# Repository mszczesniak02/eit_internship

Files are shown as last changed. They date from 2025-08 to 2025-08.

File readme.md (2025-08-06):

# EIT Internship 2025

This repository contains documentation and resources for 3D printing equipment, developed during the EIT internship program.

## Project Overview

The project encompasses two main components:

-   **Voron 3D Printer**: Operational manual, configuration files, and system backups
-   **Poseidon Liquid Dispensing System**: Modified open-source pump system with custom code adaptations and enhanced 3D models

## Repository Contents

### Voron Printer

-   Detailed user manual with troubleshooting guides
-   Configuration backups and restoration procedures
-   Test models and calibration files
-   Software setup instructions (Klipper, MainSail, KlipperScreen)

### Poseidon Pump System

-   Modified firmware and control software
-   Custom 3D printable components and enclosures
-   Calibration procedures and accuracy measurements
-   Integration guides for laboratory use

## Technical Documentation

All documentation is provided in Polish and includes:

-   Step-by-step installation procedures
-   Maintenance and troubleshooting protocols
-   Safety guidelines and best practices
-   Performance specifications and limitations

## Project Team

**Kacper Kamiński**  |  **Krzysztof Podoba**  |  **Mateusz Szczęśniak**

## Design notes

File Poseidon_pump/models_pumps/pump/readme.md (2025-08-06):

The **pump_3_base** and **pump_3_carriage** models were used to create Pump 3.
The difference in the carriage models lies in the increased wall height, which allows for a more secure hold of the syringe.

The **pump_1_2_base** and **pump_1_2_carriage** models were used to create Pump 1 and Pump 2.
The difference in the base models is the increased height of the area where the pump is mounted.

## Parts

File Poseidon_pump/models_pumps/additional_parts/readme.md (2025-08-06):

The **rod_cover** and **rod_holder** models are additional components that can be used to provide a more stable positioning of the syringe.

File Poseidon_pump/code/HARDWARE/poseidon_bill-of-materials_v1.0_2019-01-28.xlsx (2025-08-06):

Poseidon Pumps
Total for 3 pumps | $174.87 |  |  |  | Per pump total | 37.90810303
Part Number | Item Description | Package Cost | Packages for 3 pumps | Items per pump | Cost for 3 pumps | Cost per pump | Cost for single pump | Retailer | Items per pack | Price per item | Link
1 | Nema 17 Stepper Motor (Bipolar, 40mm, 45Ncm) | 33.99 | 1 | 1 | 33.99 | 11.33 | 33.99 | Amazon | 3 | 11.33 | https://www.amazon.com/Stepper-Holding-Printer-Beauty-Star/dp/B075S98D46
2 | 5mm to 5mm Motor Shaft Coupling | 22 | 1 | 1 | 22 | 2.2 | 22 | Amazon | 10 | 2.2 | https://www.amazon.com/Aluminum-Flexible-Coupling-Printing-Pack/dp/B01EFFBM4I?s=industrial
3 | 6mm Steel Rod (length 200mm, pack of 2) | 7.12 | 3 | 2 | 21.36 | 7.12 | 7.12 | Amazon | 2 | 3.56 | https://www.amazon.com/Steel-Round-Turning-Lathe-200mm/dp/B00LUSVKVY
4 | 6mm Linear Bearing (pack of 12) | 12.49 | 1 | 2 | 12.49 | 2.081666667 | 12.49 | Amazon | 12 | 1.040833333 | https://www.amazon.com/uxcell-6mmx12mmx19mm-Linear-Bushing-Bearing/dp/B01MTLSZFQ?s=industrial
5 | M5x0.8 Threaded Rod (length 170mm) | 9.14 | 1 | 1 | 9.14 | 1.828 | 9.14 | Amazon | 5 | 1.828 | https://www.amazon.com/uxcell-170mm-Stainless-Threaded-Fasteners/dp/B01M4L8JDC?s=industrial
6 | M5x0.8 nut | 7.2 | 1 | 1 | 7.2 | 0.144 | 7.2 | Amazon | 50 | 0.144 | https://www.amazon.com/uxcell-Metric-M5x0-8mm-Stainless-Finished/dp/B012T3C8YQ?s=industrial
7 | M3x0.5 socket head screws to mount motor (length 20mm) | 9.91 | 1 | 4 | 9.91 | 0.3964 | 9.91 | Amazon | 100 | 0.0991 | https://www.amazon.com/Stainless-Socket-Internal-Threaded-Threads/dp/B000FN21AO?s=industrial
8 | M3x0.5 socket head screws (hold rod in place, length 10mm) | 7.8 | 1 | 2 | 7.8 | 0.2836363636 | 7.8 | Amazon | 55 | 0.1418181818 | https://www.amazon.com/uxcell-M3x10mm-Thread-Stainless-Socket/dp/B01MFA9YEP?s=industrial
9 | M3 nut (hold rod in place) | 5.2 | 1 | 2 | 5.2 | 0.104 | 5.2 | Amazon | 100 | 0.052 | https://www.amazon.com/100Pcs-Female-Thread-Fastener-Silver/dp/B00GYS1SXU?s=industrial
10 | M5 knob (hold syringe in place) | 11.9 | 1 | 1 | 11.9 | 1.19 | 11.9 | Amazon | 10 | 1.19 | https://www.amazon.com/Kipp-06220-405X50-Thermoplastic-External-Diameter/dp/B013I72QTY?s=industrial
11 | 12V power unit (end stripped to fit CNC shield power input) | 15 | 1 | 1 | 15 | 5 | 5 | Amazon | 1 | 15 | https://www.amazon.com/Kastar-AC-Adapter-Power-LCD/dp/B003TUMDWG?s=electronics
12 | Arduino + CNC Shield Pack | 18.88 | 1 | 0.33 | 18.88 | 6.2304 | 18.88 | Amazon | 1 | 18.88 | https://www.amazon.com/Longruner-Expansion-Stepper-Heatsink-Arduino/dp/B06XJKVLG3
Poseidon Microscope
Total microscope | $180.37
Part Number | Item Description | Package Cost | Packages needed | Items needed | Cost | Items per pack | Retailer | Link
1 | Raspberry Pi Motherboard | 35.75 | 1 | 1 | 35.75 | 1 | Amazon | https://www.amazon.com/Raspberry-Pi-RASPBERRYPI3-MODB-1GB-Model-Motherboard/dp/B01CD5VC92?s=pc
2 | Raspberry Pi 7" touchscreen display | 69.99 | 1 | 1 | 69.99 | 1 | Amazon | https://www.amazon.com/Raspberry-Pi-7-Touchscreen-Display/dp/B0153R2A9I
3 | Raspberry Pi Power Suppy (5v 1.5A DC) | 9.99 | 1 | 1 | 9.99 | 1 | Amazon | https://www.amazon.com/CanaKit-Raspberry-Supply-Adapter-Charger/dp/B00MARDJZ4?s=electronics
4 | 16gb MicroSD card (comes with adapter) | 6.95 | 1 | 1 | 6.95 | 1 | Amazon | https://www.amazon.com/SanDisk-16GB-Micro-SDHC-Memory/dp/B004G605OA?s=electronics
5 | USB Microscope | 20.99 | 1 | 1 | 20.99 | 1 | Amazon | https://www.amazon.com/Jiusion-Magnification-Endoscope-Microscope-Compatible/dp/B06WD843ZM/
6 | Keyboard + Mouse Bundle (wired) | 13.09 | 1 | 1 | 13.09 | 1 | Amazon | https://www.amazon.com/AmazonBasics-Wired-Keyboard-Mouse-Bundle/dp/B00B7GV802?s=electronics
7 | M3x0.5 Socket Head Screws (length 10mm) | 7.8 | 1 | 4 | 7.8 | 55 | Amazon | https://www.amazon.com/uxcell-M3x10mm-Thread-Stainless-Socket/dp/B01MFA9YEP?s=industrial
8 | M5x0.8 Socket Head Screw (length 14mm) | 8.61 | 1 | 8 | 8.61 | 15 | Amazon | https://www.amazon.com/uxcell-M5x14mm-Stainless-Metric-Thread/dp/B01LJROXK0
9 | M5x0.8 nuts | 7.2 | 1 | 8 | 7.2 | 50 | Amazon | https://www.amazon.com/uxcell-Metric-M5x0-8mm-Stainless-Finished/dp/B012T3C8YQ?s=industrial

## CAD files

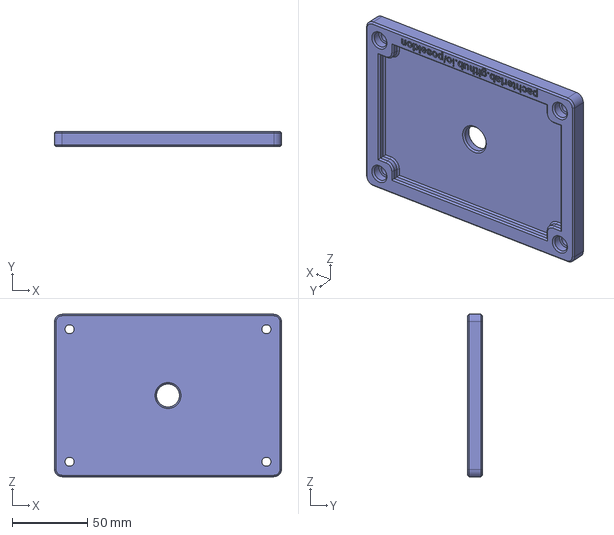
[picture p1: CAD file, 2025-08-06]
Poseidon_pump/code/HARDWARE/microscope/step/Scope Top Stage.step
151.2 x 10.0 x 108.3 mm

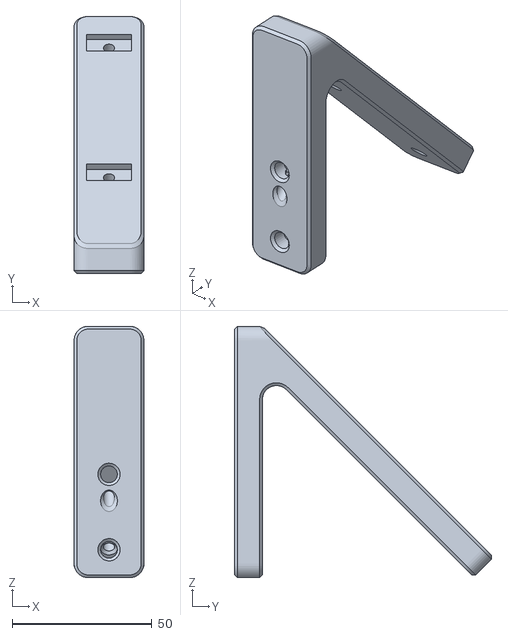
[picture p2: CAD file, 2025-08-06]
Poseidon_pump/code/HARDWARE/microscope/stl/Scope Screen Leg Mount v33.stl
25.0 x 92.0 x 90.0

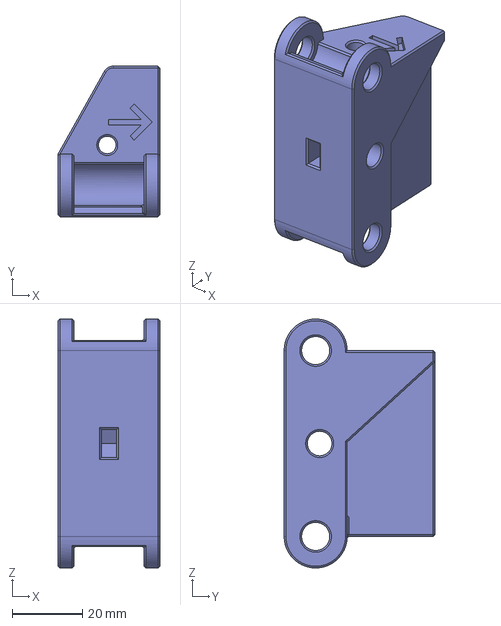
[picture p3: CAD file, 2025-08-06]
Poseidon_pump/code/HARDWARE/pump/step/Pump Carriage.step
29.0 x 43.0 x 71.0 mm

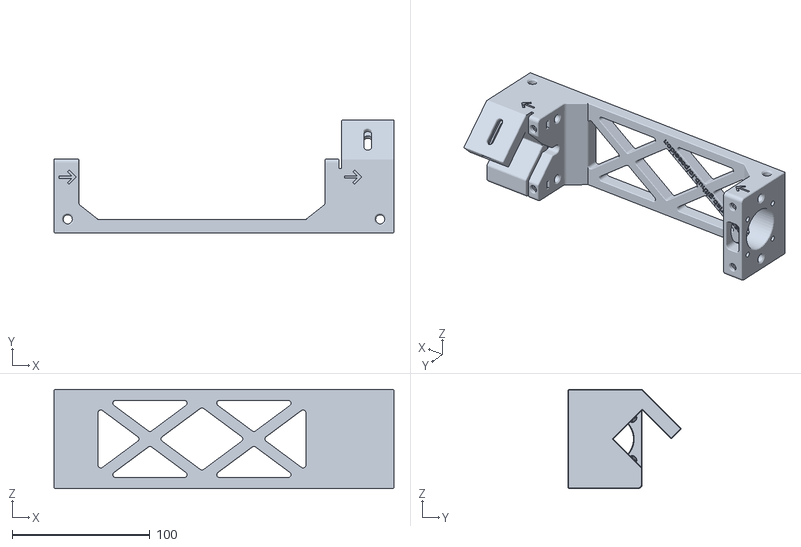
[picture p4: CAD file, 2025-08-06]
Poseidon_pump/code/HARDWARE/pump/stl/Pump Base v51.stl
247.0 x 82.3 x 72.0

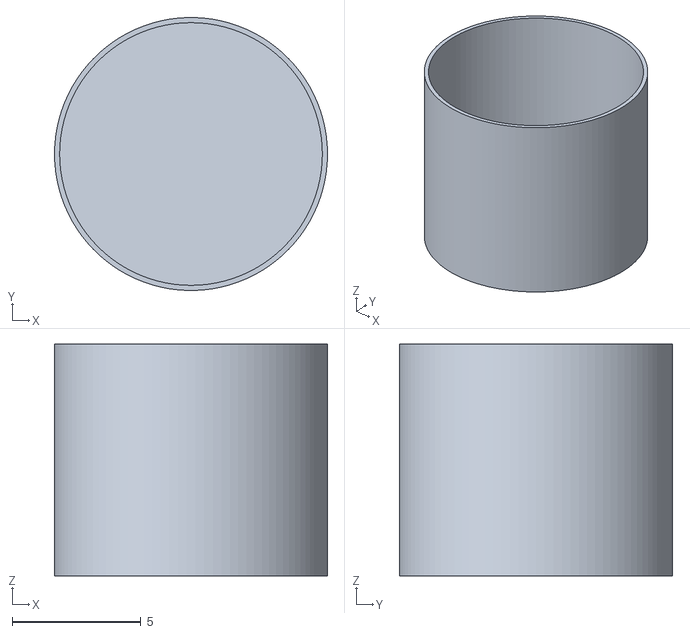
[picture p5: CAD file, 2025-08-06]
Poseidon_pump/models_pumps/additional_parts/rod_cover.stl
10.6 x 10.6 x 9.00

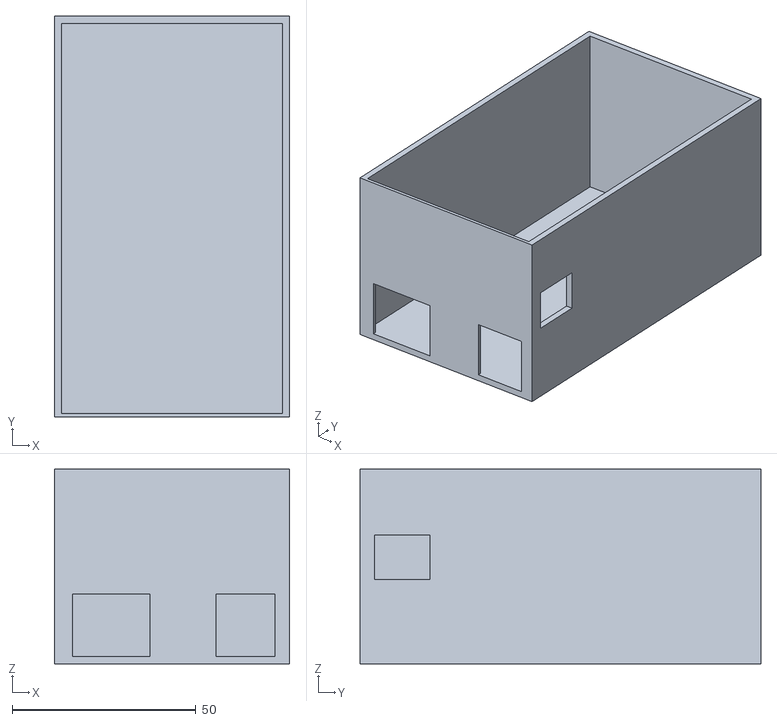
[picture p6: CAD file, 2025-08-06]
Poseidon_pump/models_pumps/arduino_case/arduino_case.stl
64.0 x 109.0 x 53.0

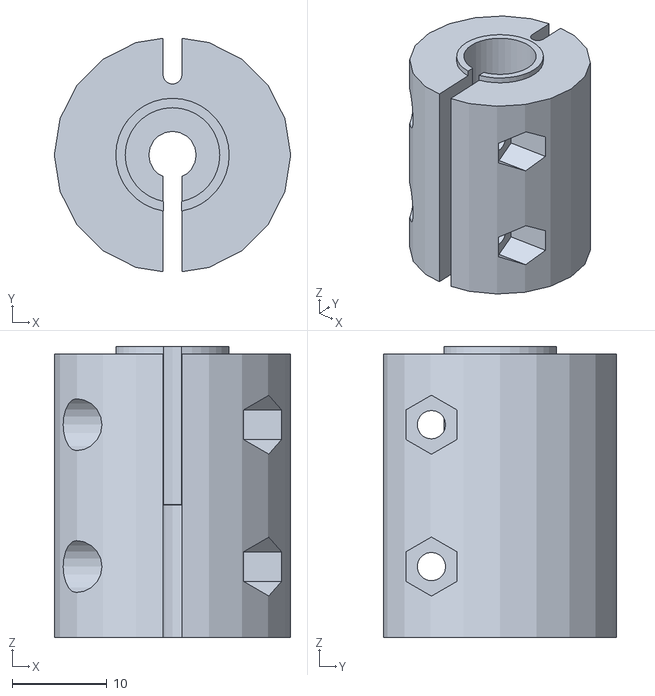
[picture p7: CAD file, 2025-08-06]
Poseidon_pump/models_pumps/pump/motor_shaft_5_10.stl
25.0 x 24.7 x 30.8

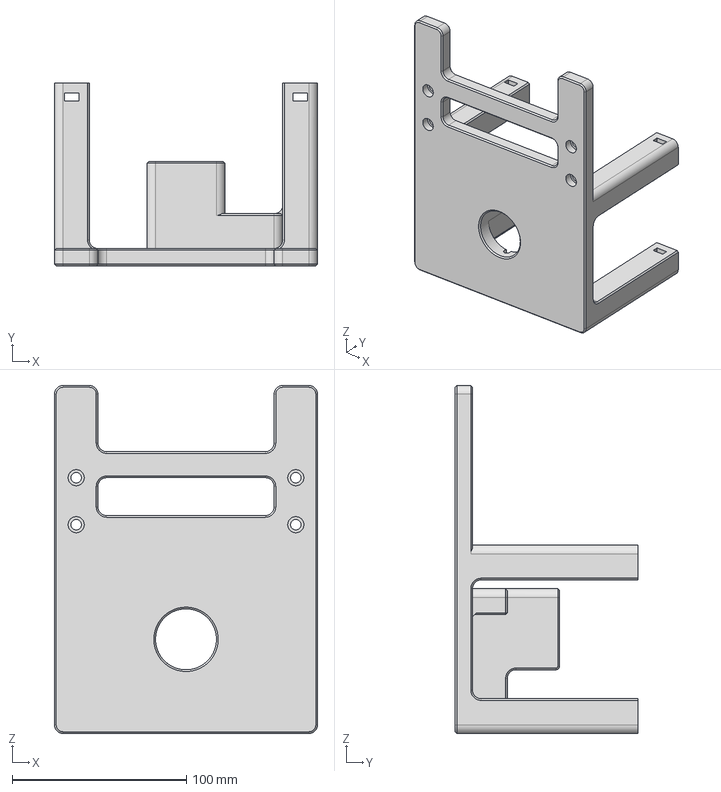
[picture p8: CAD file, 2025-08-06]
Poseidon_pump/code/HARDWARE/microscope/step/Scope Base.step
151.2 x 105.0 x 200.0 mm

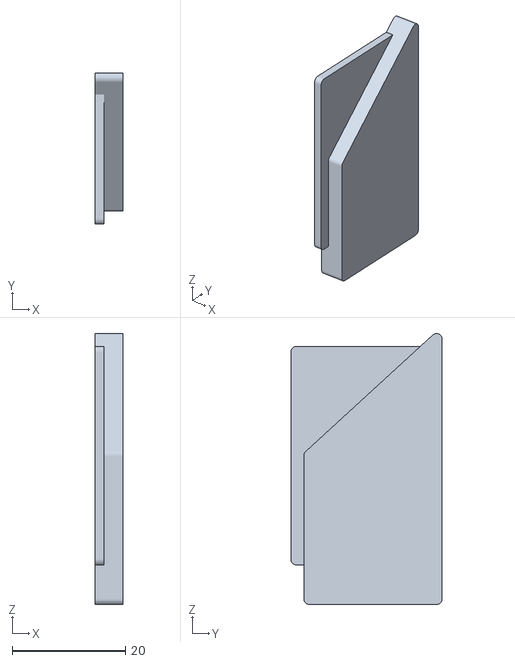
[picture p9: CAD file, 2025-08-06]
Poseidon_pump/code/HARDWARE/pump/stl/Pump Cover Slide v51.stl
5.00 x 26.8 x 47.9

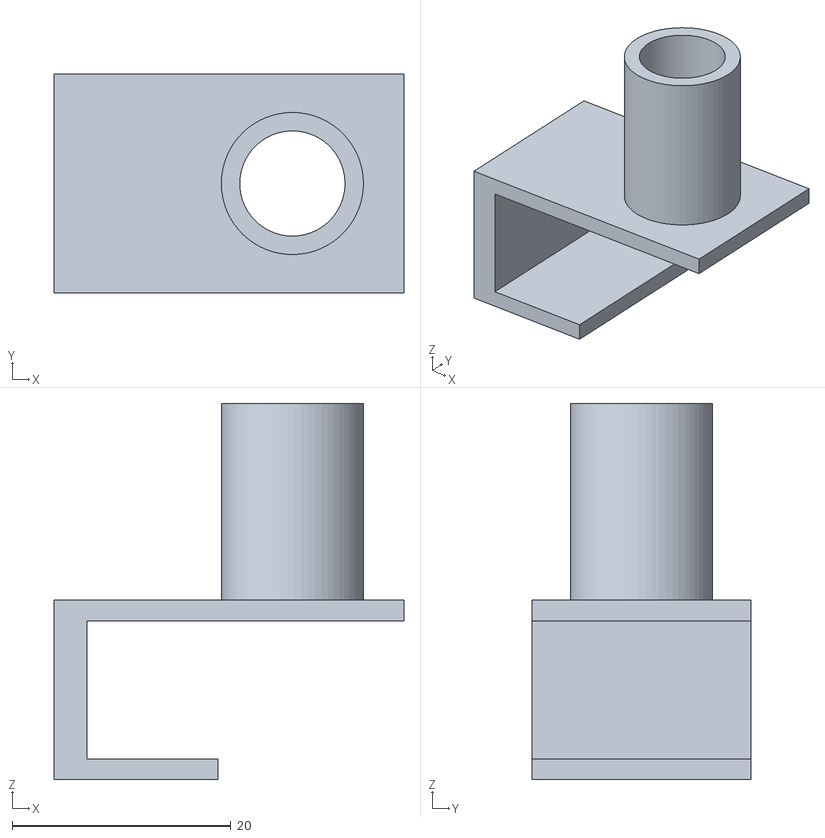
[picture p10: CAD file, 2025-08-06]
Poseidon_pump/models_pumps/additional_parts/rod_holder.stl
32.0 x 20.0 x 34.4

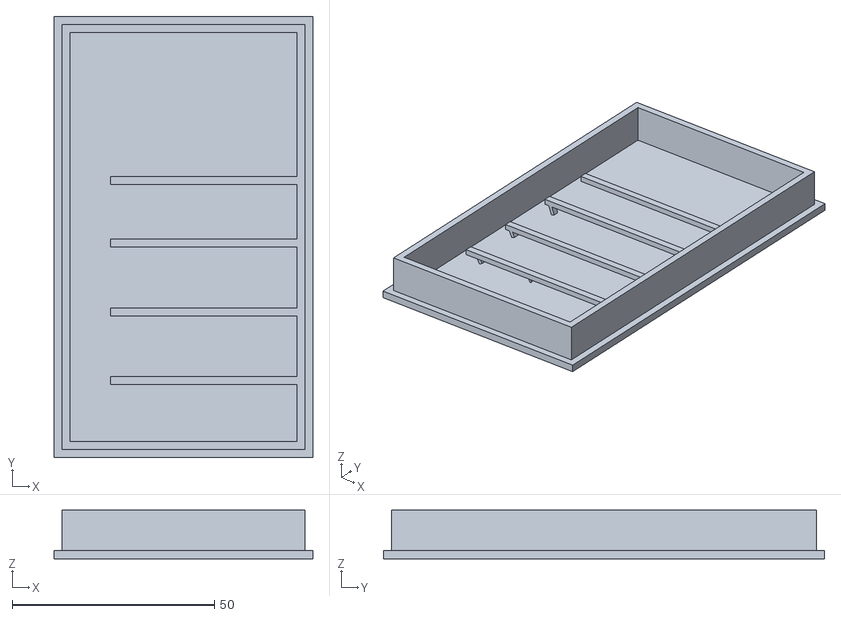
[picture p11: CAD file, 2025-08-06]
Poseidon_pump/models_pumps/arduino_case/arduino_case_cover.stl
64.0 x 109.0 x 12.0

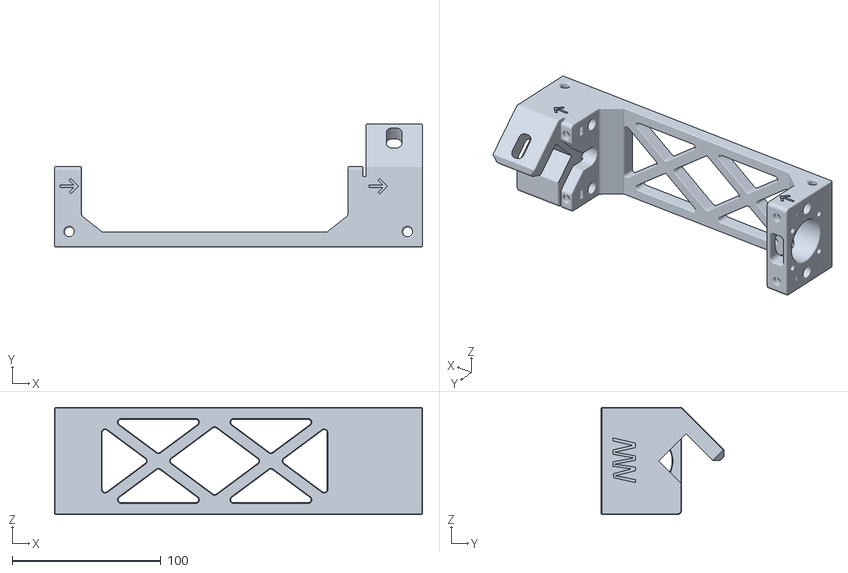
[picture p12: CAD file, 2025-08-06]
Poseidon_pump/models_pumps/pump/pump_1_2_base.stl
247.0 x 82.3 x 72.0

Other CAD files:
Poseidon_pump/code/HARDWARE/microscope/stl/Scope Base v33.stl
Poseidon_pump/code/HARDWARE/pump/step/Pump Base.step
Poseidon_pump/code/HARDWARE/microscope/step/Scope Screen Leg Mount.step
Poseidon_pump/code/HARDWARE/microscope/stl/Scope Top Stage v33.stl
Poseidon_pump/code/HARDWARE/pump/step/Pump Cover Slide.step
Poseidon_pump/code/HARDWARE/pump/stl/Pump Carriage Sled v51.stl
Poseidon_pump/code/HARDWARE/microscope/iges/Scope Base.iges
Poseidon_pump/code/HARDWARE/microscope/iges/Scope Screen Leg Mount.iges
Poseidon_pump/code/HARDWARE/microscope/iges/Scope Top Stage.iges
Poseidon_pump/code/HARDWARE/pump/iges/Pump Base.iges
Poseidon_pump/code/HARDWARE/pump/iges/Pump Base.prt
Poseidon_pump/code/HARDWARE/pump/iges/Pump Carriage.iges
Poseidon_pump/code/HARDWARE/pump/iges/Pump Carriage.prt
Poseidon_pump/code/HARDWARE/pump/iges/Pump Carriage_1.prt
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

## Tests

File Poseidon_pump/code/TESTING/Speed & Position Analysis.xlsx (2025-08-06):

1/32 Microstep | Number of Pumps Running | Set speed (mm/s) | Set Travel distance (mm) | Inferred Set Time (s) | Measured time (s) | Measured Distance (mm) | Measured Speed (mm/s) | Distance Error (mm, signed) | Distance Percent Error | Speed Error (mm/s, signed) | Percent Speed Error
1 | 1 | 0.01 | 0.1 | 10 | 10.64 | 0.1 | 0.009398496241 | 0 | 0 | -0.0006015037594 | 6.015037594
2 | 1 | 0.01 | 0.1 | 10 | 10.73 | 0.1 | 0.009319664492 | 0 | 0 | -0.0006803355079 | 6.803355079
3 | 1 | 0.01 | 0.1 | 10 | 10.54 | 0.1 | 0.009487666034 | 0 | 0 | -0.0005123339658 | 5.123339658
4 | 1 | 0.01 | 0.1 | 10 | 10.53 | 0.1 | 0.009496676163 | 0 | 0 | -0.0005033238367 | 5.033238367
5 | 1 | 0.01 | 0.1 | 10 | 10.57 | 0.1 | 0.009460737938 | 0 | 0 | -0.0005392620624 | 5.392620624
6 | 1 | 0.01 | 0.1 | 10 | 10.51 | 0.1 | 0.009514747859 | 0 | 0 | -0.0004852521408 | 4.852521408
7 | 1 | 0.01 | 0.1 | 10 | 10.54 | 0.1 | 0.009487666034 | 0 | 0 | -0.0005123339658 | 5.123339658
8 | 1 | 0.01 | 0.1 | 10 | 10.52 | 0.1 | 0.009505703422 | 0 | 0 | -0.0004942965779 | 4.942965779
9 | 1 | 0.01 | 0.1 | 10 | 10.51 | 0.11 | 0.01046622265 | -0.01 | 10 | 0.0004662226451 | 4.662226451
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

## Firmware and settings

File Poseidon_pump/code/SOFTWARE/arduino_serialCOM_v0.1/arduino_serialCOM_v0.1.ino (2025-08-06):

//#include <lc.h>
//#include <lc-addrlabels.h>
//#include <pt-sem.h>
//#include <lc-switch.h>
//#include <pt.h>

// TODO:
// (1) Figure out how to report distance remaining back to python
// (2) Combine the run and jog functions into a move function
// (3) Then also combine one, few, and all movements into 1 function
// (4) Figure out how to enable/disable steppers without using the jumper that way we can control the enabling via gui

// NOTES:
// (1) All values are reported to the arduino in steps (not mm or any other units!)
// (2) With 32 microstepping, and a 200 step motor, there are effectively 6400 steps per rev
// (3) The reporting the distance left will reutnr "steps remaining"

// WRITE COMMAND: <RUN,DIST,123,F,0.0,0.0,0.0>

// ======================================================
// ACCELSTEPPER FUNCTIONS: returns fncName(argtype arg) [description]
// ======================================================

// SETTINGS
// --------
// void setMaxSpeed(float speed>0)            [run() will accelerate to speed in steps per sec]
// void setAcceleration(float acceleration>0) [sets the accel in steps per sec per sec]
// void setSpeed(float speed)                 [runSpeed() will use this amount. >0 is clockwise, <0 counterclockwise]

// #########I DON'T USE THESE###########
// void setMinPulseWidth(unsignedint minWidth)
// void setEnablePin(uint8_t enablePin=0xff)
// void setPinsInverted(bool directionInvert=false, bool stepInvert=false, bool enableInvert=false)
// void setPinsInverted (bool pin1Invert, bool pin2Invert, bool pin3Invert, bool pin4Invert, bool enableInvert)
// #########I DON'T USE THESE###########

// SET MOVEMENT
// ------------
// void moveTo(long absolute)
// void move(long relative)
// void setCurrentPosition(long position)      [resets the current position of the motor to ZERO. this is the ZERO!! side effect: sets speed=0]

// RUN
// -----------
// void runToPosition()                        [BLOCKING; moves with accel and decell to target (runToNewPosition()) calls this fnc, then this calls run()]
// void runToNewPosition(long position)        [BLOCKING; moves with accel and deccel to target position (absolute position) moves with run()]
// bool run()                                  [move motor one step if a step is due. this implements accel and decell. uses setMaxSpeed]
// bool runSpeed()                             [move motor one step if a step is due. does not implement accel and decell (ie inf accel). uses setSpeed()]
// bool runSpeedToPosition()                   [runs at currently selected speed until target position is reached, does not use accel]
// void stop()                                 [changes target pos s.t. stepper stops as quickly as possible. uses accel and decell]
// void disableOutputs()
// void enableOutputs()

// I am confused how the calls work for these functions. need to review

// GETTERS
// ------------
// long distanceToGo()                         [returns distance in steps from targetPosition. >0 is clockwise from current pos, <0 ccw]
// long targetPosition()                       [the most recently set target pos, >0 is cw from the ZERO and <0 is ccw from current]
// long currentPosition()                      [current motor position >0 cw from the ZERO position
// bool isRunning()
// float maxSpeed()
// float speed()

// =============================== Code starts here ================================================================

#include <AccelStepper.h>

// First we create the constants that we will use throughout our code
#define MOTOR_STEPS 200 
#define MICROSTEPS 32
#define TOTAL_STEPS 6400 

#define X_SPEED 1000 // X steps per second
#define Y_SPEED 1000 // Y
#define Z_SPEED 1000 // Z

#define X_ACCEL 5000.0 // X steps per second per second
#define Y_ACCEL 5000.0 // Y
#define Z_ACCEL 5000.0 // Z

#define EN        8       // stepper motor enable, low level effective (note put jumper so automatic)

#define X_DIR     5       // X axis, direction pin
#define Y_DIR     6       // Y
#define Z_DIR     7       // Z

#define X_STP     2       // X axis, step pin
#define Y_STP     3       // Y
#define Z_STP     4       // Z

#define BAUD_RATE 230400  // the rate at which data is read

// AccelStepper is the class we use to run all of the motors in a parallel fashion
// Documentation can be found here: http://www.airspayce.com/mikem/arduino/AccelStepper/classAccelStepper.html
AccelStepper stepper1(AccelStepper::DRIVER, X_STP, X_DIR);
AccelStepper stepper2(AccelStepper::DRIVER, Y_STP, Y_DIR);
AccelStepper stepper3(AccelStepper::DRIVER, Z_STP, Z_DIR);


// Now we declare variables we will use throughout our code (That could change!)
const int ledPin = 13;
// The buffer allows us to store bytes as they are read from the python program (64 bytes in size)
const byte buffSize = 64;
char inputBuffer[buffSize];
// We create inputs to this program by <...> where <> represent the startread and endread markers
const char startMarker = '<';
const char endMarker = '>';

byte bytesRecvd = 0;
boolean readInProgress = false;
boolean newDataFromPC = false;

// WRITE COMMAND: <RUN,DIST,123,F,0.0,0.0,0.0>
// The following is data we will read from the PC. Since the USB reads one byte at a time, we have to store a
// string of bytes in an array called messageFromPC. Then we can grab the relevant information from it.
// Note that in this application, a command sent from python takes the form: <mode, setting, motorID, value, direction, optional>
// Where mode is ["RUN", "SETTING", "JOG", "STOP"]
// setting is string ["ALL"", "FEW", "ONE", "ACCEL", "SPEED", "DELTA"]
// motorID is int [1, 2, 3] (can be combo if numbers ie 123 or 12 or 23)
// value is float [any positive floating number]
// direction is ['F', 'B']
// p1_optional is [any floating number]
// p2_optional is [any floating number]
// p3_optional is [any floating number]

char messageFromPC[buffSize] = {0};
char mode[buffSize] = {0};
int motorID = 0;
int motors[3] = {0,0,0};
AccelStepper steppers[3] = {stepper1, stepper2, stepper3};
char setting[buffSize] = {0};
float value = 0.0;
char dir[buffSize] = {0};
float optional = 0.0;

// These are values that we declare to assign as "settings" to each of the steppers
float motorSpeed = 0.0;
float motorAccel = 0.0;
float oldDistanceLeft1;
float oldDistanceLeft2;
float oldDistanceLeft3;
float jog1Delta;
float jog2Delta;
float jog3Delta;
float toMove;
float p1_toMove;
float p2_toMove;
float p3_toMove;
float p1_optional;
float p2_optional;
float p3_optional;
float distances[3];
signed long p1_distance_to_go;
signed long p1_target_position;
signed long p1_distance_left;

signed long p2_distance_to_go;
signed long p2_target_position;
signed long p2_distance_left;

signed long p3_distance_to_go;
signed long p3_target_position;
signed long p3_distance_left;

signed long distances_to_go[3];
signed long targets_position[3];
signed long distances_left[3];

unsigned long curMillis;
unsigned long prevReplyToPCmillis = 0;
unsigned long replyToPCinterval = 1000;

//=============
// Setup is only called once. When we start up the GUI the Arduino initalizes with a BAUD Rate of _________
void setup() {
  Serial.begin(BAUD_RATE);

  // flash LEDs so we know we are alive
  pinMode(ledPin, OUTPUT);
  digitalWrite(ledPin, HIGH);
  delay(500); // delay() is OK in setup as it only happens once
  digitalWrite(ledPin, LOW);
  delay(500);

  stepper1.setMaxSpeed(X_SPEED);
  stepper2.setMaxSpeed(Y_SPEED);
  stepper3.setMaxSpeed(Z_SPEED);
  // stepper1.setSpeed(X_SPEED);
  // stepper2.setSpeed(Y_SPEED);
  // stepper3.setSpeed(Z_SPEED);
  stepper1.setAcceleration(X_ACCEL);
  stepper2.setAcceleration(Y_ACCEL);
  stepper3.setAcceleration(Z_ACCEL);
  // tell the PC we are ready
  Serial.println("<Arduino is ready>");


}

//=============
// The loop function is what is always running and refreshes BAUD_RATE times per second
void loop() {
  curMillis = millis();
  getDataFromPC();
  // Now is when we determine which mode we are in which dictates which function to call
  //replyToPC();
  //executeThisFunction();
  //replyToPC();
}

//=============
// Here we get data from the serial port, read it one byte at a time, store each subsequent byte in the buffer (list)
// then read it and declare the values to variables in this code
void getDataFromPC() {

  // If there is data from the serial port
  if (Serial.available() > 0) {
    // turn on the LED to indicate we are receiving
    digitalWrite(ledPin, HIGH);
    // read the a single character
    char x = Serial.read();

    // the order of these IF clauses is significant
    if (x == endMarker) {
      readInProgress = false;
      newDataFromPC = true;
      // clear the buffer
      inputBuffer[bytesRecvd] = 0;
      // and parse the data
      return parseData();
    }

    if (readInProgress) {
      // add the character to the buffer
      inputBuffer[bytesRecvd] = x;
      bytesRecvd ++;
      if (bytesRecvd == buffSize) {
        bytesRecvd = buffSize - 1;
      }
    }

    if (x == startMarker) {
      bytesRecvd = 0;
      readInProgress = true;
    }
    digitalWrite(ledPin, LOW);
  }
}


//=============

/*
  # <Mode, Setting, Pump Num, Value>
  # Mode can be SETTING, RUN, JOG, STOP
  # Setting can be SPEED, ACCEL, DELTA, ONE, FEW, ALL, ZERO
  # Pump number can be 1 or 2 or 3 or 12 or 13 or 23. (## indicates two pumps to run)
*/

// Here is where we take the string <...> that we have read from the serial port and parse it
void parseData() {

  // split the data into its parts
  // strtok scans the string inputBuffer until it reaches a "," or a ">"
  // Then we declare the variable associated with that part of the inputBuffer
  // each strtok contiues where the previous call left off

  char * strtokIndx; // this is used by strtok() as an index


  strtokIndx = strtok(inputBuffer, ",");     // get the first part - the mode string
  strcpy(mode, strtokIndx);                  // copy it to messageFromPC

  strtokIndx = strtok(NULL, ",");            // get the second part - the setting string
  strcpy(setting, strtokIndx);               // copy it to messageFromPC


  strtokIndx = strtok(NULL, ",");            // get the third part - the motor ID int
  String motorstr(strtokIndx);

  motorID = atoi(strtokIndx);                // convert to integer and copy it to motorID

  motors[0] = 0;
  motors[1] = 0;
  motors[2] = 0;

  if(motorstr.indexOf("1") >= 0) {
    motors[0] = 1;
  }
  if(motorstr.indexOf("2") >= 0) {
    motors[1] = 1;
  }
  if(motorstr.indexOf("3") >= 0) {
    motors[2] = 1;
  }
  Serial.println("string");
  Serial.println(motorstr);
  Serial.println("Status");
  Serial.println(motors[0]);
  Serial.println(motors[1]);
  Serial.println(motors[2]);

  strtokIndx = strtok(NULL, ",");            // get the fourth part - the value float
  value = atof(strtokIndx);                  // convert to float and copy to value

  strtokIndx = strtok(NULL, ",");            // get the fifth part - the direction character
  strcpy(dir, strtokIndx);                   // copy the character to dire

  strtokIndx = strtok(NULL, ",");            // get the fourth part - the value float
  p1_optional = atof(strtokIndx);            // convert to float and copy to value

  strtokIndx = strtok(NULL, ",");            // get the fourth part - the value float
  p2_optional = atof(strtokIndx);            // convert to float and copy to value

  strtokIndx = strtok(NULL, ",");            // get the fourth part - the value float
  p3_optional = atof(strtokIndx);            // convert to float and copy to value

  distances[0] = p1_optional;
  distances[1] = p2_optional;
  distances[2] = p3_optional;
  if (strcmp(setting, "RUN") == 0) {
    distances[0] = 999999.0;
    distances[1] = 999999.0;
    distances[2] = 999999.0;
  }

  Serial.println("Status Distances");
  Serial.println(distances[0]);
  Serial.println(distances[1]);
  Serial.println(distances[2]);

  newDataFromPC = true;
  replyToPC();

  return executeThisFunction();
  }

void clearVariables() {
  char messageFromPC[buffSize] = {0};
  char mode[buffSize] = {0};
  char setting[buffSize] = {0};
  int motorID = 0;
  float value = 0.0;
  char dir[buffSize] = {0};

  float p1_optional = 0.0;
  float p2_optional = 0.0;
  float p3_optional = 0.0;
}

// =============================
// So we do a string comparison using strcmp(str1, str2) as a condition to determine what to do next
// Here we can add new functions if we like, for example if we wanted to add a "TEST" to the mode
// input we would add a condition if (strcmp(mode, "TEST") == 0 {...}
void executeThisFunction() {

  if (strcmp(mode, "STOP") == 0) {
    return stopAll();
  }

  else if (strcmp(mode, "SETTING") == 0) {
    return udpateSettings();
    //Serial.print("UPDATING SETTINGS\n");
  }

  else if (strcmp(mode, "RUN") == 0) {
    // Check if any stepper is currently running and do not allow execution if that is the case
    //if (!stepper1.isRunning()) {
      if (strcmp(setting, "DIST") == 0) {
        return runFew();
     // }
    }

  }

  else if (strcmp(mode, "PAUSE") == 0) {
    return pauseRun();
  }

  else if (strcmp(mode, "RESUME") == 0) {
    return runFew();
  }
}

//=============

// Here is where we reply to the PC if we find that we have new data from the PC
// This is executed on everyloop if we detect that we have new data from the pc

void replyToPC() {

  if (newDataFromPC) {
    newDataFromPC = false;
    Serial.print("<mode: ");
    Serial.print(mode);
    Serial.print(" ,setting: ");
    Serial.print(setting);
    Serial.print(" ,motorID: ");
    Serial.print(motorID);
    Serial.print(" ,value: ");
    Serial.print(value);
    Serial.print(" ,direction: ");
    Serial.print(dir);
    Serial.print(" ,p1 optional: ");
    Serial.print(p1_optional);
    Serial.print(" ,p2 optional: ");
    Serial.print(p2_optional);
    Serial.print(" ,p3 optional: ");
    Serial.print(p3_optional);
    Serial.print(" ,Time ");
    Serial.print(curMillis >> 9); // divide by 512 is approx = half-seconds
    Serial.println(">");
  }
  //executeThisFunction();
}


// Here we want to send our current distance to the PC
// We send the motor ID and then print out distance left
// This returns the step difference between where we are at now and where we want to be.
// Since the Baud Rate is larger than the speed of rotation for max motor speed
// we return the distance left only if it changes otherwise it would print out the same
// number a million times
void sendDistanceToPC(int mID) {
  switch (mID) {
    case 1:
      if (stepper1.distanceToGo() != oldDistanceLeft1) {
        Serial.print("<DISP1|");
        Serial.print(stepper1.distanceToGo());
        Serial.print(">");
      }
      oldDistanceLeft1 = stepper1.distanceToGo();
      break;
    case 2:
      if (stepper2.distanceToGo() != oldDistanceLeft2) {
        Serial.print("<DISP2|");
        Serial.print(stepper2.distanceToGo());
        Serial.print(">");
      }
      oldDistanceLeft2 = stepper2.distanceToGo();
      break;
    case 3:
      if (stepper3.distanceToGo() != oldDistanceLeft3) {
        Serial.print("<DISP3|");
        Serial.print(stepper3.distanceToGo());
        Serial.print(">");
      }
      oldDistanceLeft3 = stepper3.distanceToGo();
      break;
  }
}
//============
// Update the settings for each stepper. This is run before performing any moving functions
// It sets the speed, accel, and jog delta for each pump

void udpateSettings() {
  stepper1.setCurrentPosition(0.0);
  stepper2.setCurrentPosition(0.0);
  stepper3.setCurrentPosition(0.0);

  switch (motorID) {
    case 1:
      if (strcmp(setting, "SPEED") == 0) {
        stepper1.setMaxSpeed(value);
      }
      else if (strcmp(setting, "ACCEL") == 0) {
        //stepper1.setAcceleration(value);
        stepper1.setAcceleration(value);
      }
      else if (strcmp(setting, "DELTA") == 0) {
        jog1Delta = value;
      }
      break;
    case 2:
      if (strcmp(setting, "SPEED") == 0) {
        stepper2.setMaxSpeed(value);
      }
      else if (strcmp(setting, "ACCEL") == 0) {
        //stepper2.setAcceleration(value);
        stepper2.setAcceleration(value);
      }
      else if (strcmp(setting, "DELTA") == 0) {
        jog2Delta = value;
      }
      break;
    case 3:
      if (strcmp(setting, "SPEED") == 0) {
        stepper3.setMaxSpeed(value);
      }
      else if (strcmp(setting, "ACCEL") == 0) {
        //stepper3.setAcceleration(value);
        stepper3.setAcceleration(value);
      }
      else if (strcmp(setting, "DELTA") == 0) {
        jog3Delta = value;
      }
      break;
  }
  clearVariables();
}

//======================================
// The main function for moving the pumps. Takes in a displacement (in steps) and then moves that much
// For now this is implemented in a constant speed (acceleration is zero except for start and stop where it is max)
// anytime you are running your pumps you should always calll get data from PC in case you want to send a STOP command
// This should be complete!
// Need to add the ability to report distance remaining back to LCD monitor


//===================================
// This function will run few ie if (p1, p2) or (p1, p3) or (p2, p3) are enabled
int array_sum(int * array, int len) {
  int arraySum;

  arraySum = 0;
  for(int index = 0; index < len; index++)
  { arraySum += array[index]; }
  return arraySum;
}

void runFew() {
  // First we determine the direction of movement. If 1, then it's forward, otherwise it's -1.
  // We use 1 and -1 so that we can multiply any number and reverse the math, minimizing lines of code
  AccelStepper steppers[3] = {stepper1, stepper2, stepper3};

  int direction = 1;
  if (strcmp(dir, "B") == 0) {
    direction = -1;
  }
  Serial.print("Direction");
  Serial.println(direction);
  // Second we set the distance to move for each stepper.
  // We use direction and multiply the value saved in the distances array;
  // The distances array is set above to default to 999999 if 'RUN' else, the value set.
  Serial.println("Status Distances");
  Serial.println(distances[0]);
  Serial.println(distances[1]);
  Serial.println(distances[2]);

  for (int i = 0; i < 3; i += 1) {
    if (motors[i] == 1) {
      toMove = direction * distances[i];
      Serial.print("Sedding tomove command: ");
      Serial.println(toMove);
      steppers[i].move(toMove);
    }
  }
  // Finally the main loop where we move and check the steppers status
  // We declare an array to store the status of each stepper
  int stepperStatus[3] = {0, 0, 0};
  // Then we loop until that sum is equal to the number of selected steppers
  // That number is stored in the motors array, 1 for selected, 0 otherwise
  // If we have 1 and 3 for example motors = [1, 0, 1] => sum = 2
  Serial.println("Entering While Loop ");
  Serial.println(array_sum(stepperStatus, 3));

  Serial.println(motors[0]);
  Serial.println(motors[1]);
  Serial.println(motors[2]);

  Serial.println(array_sum(motors, 3));

// 4000 steps == 1 mm


  while (array_sum(stepperStatus, 3) != array_sum(motors, 3)) {
    // We iterate over the 3 possible steppers
    for (int i = 0; i < 3; i += 1) {
      // If this stepper is selected
      if (motors[i] == 1) {
        // Ask the stepper to move to position at constant speed.
        if (stepperStatus[i] == 0 ) {
          steppers[i].run();
        }
        // Check if it reached it's position
        if (steppers[i].distanceToGo() == 0) {
          // If yes then store that value in the stepperStatus array.
          stepperStatus[i] = 1;
        }
      }
    }
    getDataFromPC();
  }
  clearVariables();
}


void stopAll() {
  for (int i = 0; i < 3; i += 1) {
    steppers[i].stop();
  }
}

void pauseRun() {
  for (int i = 0; i < 3; i += 1) {
    distances_to_go[i] = steppers[i].distanceToGo();
    targets_position[i] = steppers[i].targetPosition();
    distances_left[i] = distances_to_go[i] - distances_left[i];
    steppers[i].move(p1_distance_to_go);
  }
  while (strcmp(mode, "RESUME") != 0) {
    // do nothing
    getDataFromPC();
  }
  for (int i = 0; i < 3; i += 1) {
    distances[i] = distances_left[i];
  }

  return runFew();
}

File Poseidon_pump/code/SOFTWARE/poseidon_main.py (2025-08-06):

#!/usr/bin/env python
# -*- coding: utf-8 -*-

import serial
import time
import glob
import sys
from datetime import datetime
import time
import os
# This gets the Qt stuff

from PyQt5 import QtCore, QtGui, QtWidgets
from PyQt5.QtWidgets import QMainWindow, QApplication, QFileDialog

import cv2
# note, had to use version 3.2.0.8 otherwise it had its own
# pyqt packages that conflicted with mine

import numpy as np
from decimal import Decimal
# This is our window from QtCreator
import poseidon_controller_gui
import pdb
import traceback, sys

# ##############################
# MULTITHREADING : SIGNALS CLASS
# ##############################
class WorkerSignals(QtCore.QObject):
    '''
    Defines the signals available from a running worker thread.

    Supported signals are:

    finished
        No data

    error
        `tuple` (exctype, value, traceback.format_exc() )

    result
        `object` data returned from processing, anything

    '''
    finished = QtCore.pyqtSignal()
    error = QtCore.pyqtSignal(tuple)
    result = QtCore.pyqtSignal(object)
    progress = QtCore.pyqtSignal(int)

# #############################
# MULTITHREADING : WORKER CLASS
# #############################


class Thread(QtCore.QThread):
	def __init__(self, fn, *args, **kwargs):
		parent = None
		super(Thread, self).__init__(parent)
		self.runs = True
		self.fn = fn
		self.args = args
		self.kwargs = kwargs
		self.signals = WorkerSignals()

		self.correction_factor = 0.9388138339773648  # dla pompy 1
		

	def run(self):
		try:
			#self.serial.flushInput()
			#self.serial.flushOutput()
			result = self.fn(*self.args, **self.kwargs)
		except:
			traceback.print_exc()
			exctype, value = sys.exc_info()[:2]
			self.signals.error.emit((exctype, value, traceback.format_exc()))
		else:
			self.signals.result.emit(result)  # Return the result of the processing
		finally:
			self.signals.finished.emit()  # Done
			self.stop()

			print("Job completed")

	def stop(self):
		self.runs = False




# #####################################
# ERROR HANDLING : CANNOT CONNECT CLASS
# #####################################
class CannotConnectException(Exception):
	pass

# #######################
# GUI : MAIN WINDOW CLASS
# #######################
class MainWindow(QtWidgets.QMainWindow, poseidon_controller_gui.Ui_MainWindow):

	# =======================================================
	# INITIALIZING : The UI and setting some needed variables
	# =======================================================
	def __init__(self):

		# Setting the UI to a class variable and connecting all GUI Components
		super(MainWindow, self).__init__()
		self.ui = poseidon_controller_gui.Ui_MainWindow()
		self.ui.setupUi(self)

		# Put comments here
		self.populate_microstepping()
		self.populate_syringe_sizes()
		self.populate_pump_jog_delta()
		self.populate_pump_units()
		self.setting_variables()
		self.populate_ports()
		self.set_port()



		self.connect_all_gui_components()
		self.grey_out_components()

		# Declaring start, mid, and end marker for sending code to Arduino
		self.startMarker = 60# <
		self.endMarker = 62  # ,F,0.0>
		self.midMarker = 44 # ,

		# Initializing multithreading to allow parallel operations
		self.threadpool = QtCore.QThreadPool()
		print("Multithreading with maximum %d threads" % self.threadpool.maxThreadCount())


		# Camera setup
		self.timer = QtCore.QTimer()
		self.timer.setInterval(1000)
		self.timer.timeout.connect(self.recurring_timer)
		self.timer.start()
		self.counter = 0

		# Random other things I need
		self.image = None
		#self.microstepping = 1
		#print(self.microstepping)


	def recurring_timer(self):
		self.counter +=1

	# =============================
	# SETTING : important variables
	# =============================
	def setting_variables(self):

		self.set_p1_syringe()
		self.set_p2_syringe()
		self.set_p3_syringe()



		#self.set_p1_units()
		#self.set_p2_units()
		#self.set_p3_units()

		self.is_p1_active = False
		self.is_p2_active = False
		self.is_p3_active = False

		self.experiment_notes = ""

	def thread_finished(self, th):
		print("Your thread has completed. Now terminating..")
		th.stop()
		print("Thread has been terminated.")
		print("=============================\n\n")
		# here is where you need to end the thread


	# ===================================
	# CONNECTING : all the GUI Components
	# ===================================
	def connect_all_gui_components(self):

		# ~~~~~~~~~~~~~~~
		# MAIN : MENU BAR
		# ~~~~~~~~~~~~~~~
		self.ui.load_settings_BTN.triggered.connect(self.load_settings)
		self.ui.save_settings_BTN.triggered.connect(self.save_settings)

		# ~~~~~~~~~~~~~~~~
		# TAB : Controller
		# ~~~~~~~~~~~~~~~~

		# Px active checkboxes
		self.ui.p1_activate_CHECKBOX.stateChanged.connect(self.toggle_p1_activation)
		self.ui.p2_activate_CHECKBOX.stateChanged.connect(self.toggle_p2_activation)
		self.ui.p3_activate_CHECKBOX.stateChanged.connect(self.toggle_p3_activation)

		# Px display (TODO)

		# Px syringe display
		self.ui.p1_syringe_DROPDOWN.currentIndexChanged.connect(self.display_p1_syringe)
		self.ui.p2_syringe_DROPDOWN.currentIndexChanged.connect(self.display_p2_syringe)
		self.ui.p3_syringe_DROPDOWN.currentIndexChanged.connect(self.display_p3_syringe)


		# Px speed display
		self.ui.p1_units_DROPDOWN.currentIndexChanged.connect(self.display_p1_speed)
		self.ui.p2_units_DROPDOWN.currentIndexChanged.connect(self.display_p2_speed)
		self.ui.p3_units_DROPDOWN.currentIndexChanged.connect(self.display_p3_speed)



		#self.populate_pump_units()

		# Px amount
		self.ui.p1_amount_INPUT.valueChanged.connect(self.set_p1_amount)
		self.ui.p2_amount_INPUT.valueChanged.connect(self.set_p2_amount)
		self.ui.p3_amount_INPUT.valueChanged.connect(self.set_p3_amount)

		# Px jog delta
		#self.ui.p1_jog_delta_INPUT.valueChanged.connect(self.set_p1_jog_delta)
		#self.ui.p2_jog_delta_INPUT.valueChanged.connect(self.set_p2_jog_delta)
		#self.ui.p3_jog_delta_INPUT.valueChanged.connect(self.set_p3_jog_delta)

		# Action buttons
		self.ui.run_BTN.clicked.connect(self.run)


		self.ui.pause_BTN.clicked.connect(self.pause)


		self.ui.zero_BTN.clicked.connect(self.zero)
		self.ui.stop_BTN.clicked.connect(self.stop)


		self.ui.jog_plus_BTN.clicked.connect(lambda:self.jog(self.ui.jog_plus_BTN))
		self.ui.jog_minus_BTN.clicked.connect(lambda:self.jog(self.ui.jog_minus_BTN))

		# Set coordinate system
		self.ui.absolute_RADIO.toggled.connect(lambda:self.set_coordinate(self.ui.absolute_RADIO))
		self.ui.incremental_RADIO.toggled.connect(lambda:self.set_coordinate(self.ui.incremental_RADIO))

		# ~~~~~~~~~~~~
		# TAB : Camera
		# ~~~~~~~~~~~~

		# Setting camera action buttons
		self.ui.camera_connect_BTN.clicked.connect(self.start_camera)
		self.ui.camera_disconnect_BTN.clicked.connect(self.stop_camera)
		self.ui.camera_capture_image_BTN.clicked.connect(self.save_image)

		# ~~~~~~~~~~~
		# TAB : Setup
		# ~~~~~~~~~~~
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

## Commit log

2025-08-06 added code
    [1_poseidon.csv, 2_harvard.csv, 3_harvard.csv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]
2025-08-06 manual pump
2025-08-06 pump models
    [motor_shaft_5_10.stl, pump_1_2_base.stl, pump_1_2_carriage.stl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]
2025-08-06 arduino case
    [arduino_case.stl, arduino_case_cover.stl]
2025-08-06 additional parts for syringe stabilization
    [rod_cover.stl, rod_holder.stl]
